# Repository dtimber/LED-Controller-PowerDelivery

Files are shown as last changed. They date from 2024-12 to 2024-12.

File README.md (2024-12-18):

# LED-Controller-PowerDelivery
ESP8266 LED Controller with USB PD input for WS2812B/SK6812 LEDs specially made for monitor backlighting with [WLED](https://kno.wled.ge/) and [Lightpack](https://github.com/psieg/Lightpack).

[Video example @ YouTube](https://youtu.be/EE_DajBsjAQ)

LED Controller can be attached to VESA 75 / 100 monitor mount using the case included in this repo:

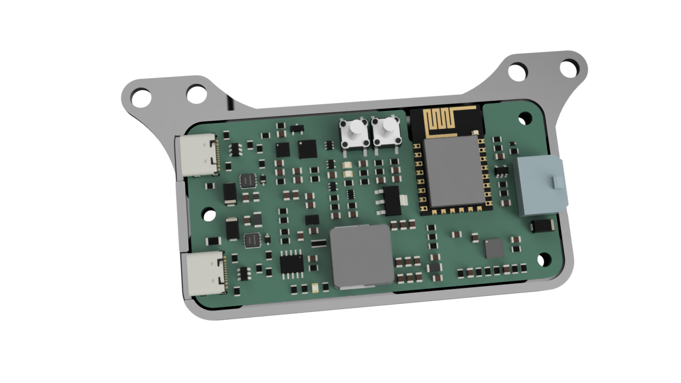
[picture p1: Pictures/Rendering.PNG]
Front


**Features:**
* Integrated 5 V buck converter for output currents up to 5 A (25 W). Minimizes risk of LED flickering / wrong colors caused by voltage drop by power supply cables, connectors, etc.
* Firmware can be flashed without additional USB PD supply connected to J1. Simply use J2 for programming.
* Single cable connection (power + data) possible via J1 (for PCs with USB PD compatible motherboards / extension cards [e.g. Inateck KU8212 / Delock 89001])
* LED power output protected by electronic fuse (output will be cut off if current is > 5 A / auto-retry after 400 ms)

**Required WLED GPIO Settings:**
* GPIO2 -> LED data output
* GPIO15 -> LED power output (WLED relay function)

**Additional Parts required:**
* 1x USB Power Delivery Supply with at least 30 W (15 V / 2 A)
* 1x USB Type C to C cable
* 3x M3 insert nuts (outer diameter: 4.6 mm / length: 6 mm) for the case
* 3x M3 screws (countersunk head e.g. ISO 10642 / length: 12 mm) for the case
* 1x connector 538-43645-0300 for the LED stripe cable
* 3x contacts 43030-0007 for the LED stripe cable

**Measured buck converter efficiency:**

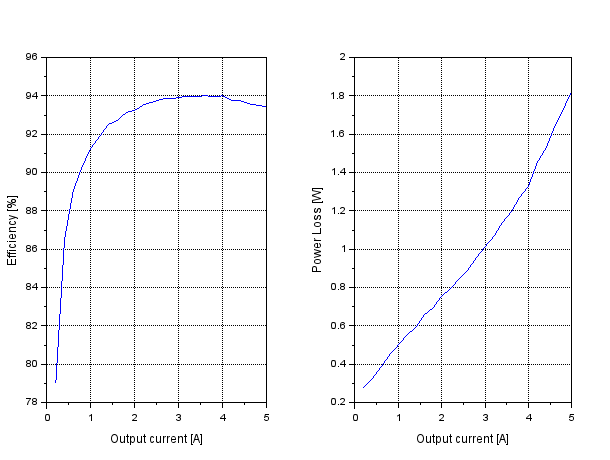
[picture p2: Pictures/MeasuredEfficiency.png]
Efficiency


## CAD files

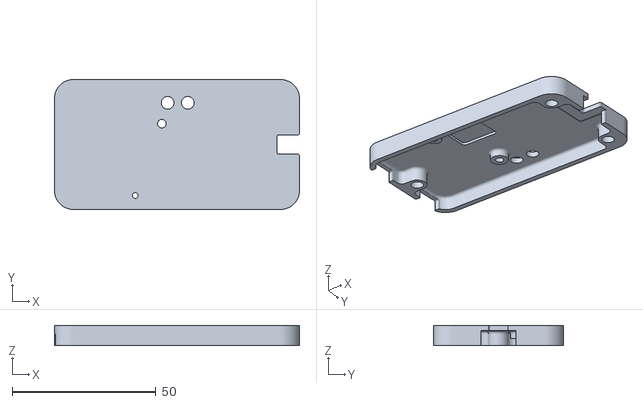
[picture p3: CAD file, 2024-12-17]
Case/LED-Controller-PD-UpperCase-Rev1.2.stl
85.2 x 45.2 x 7.00

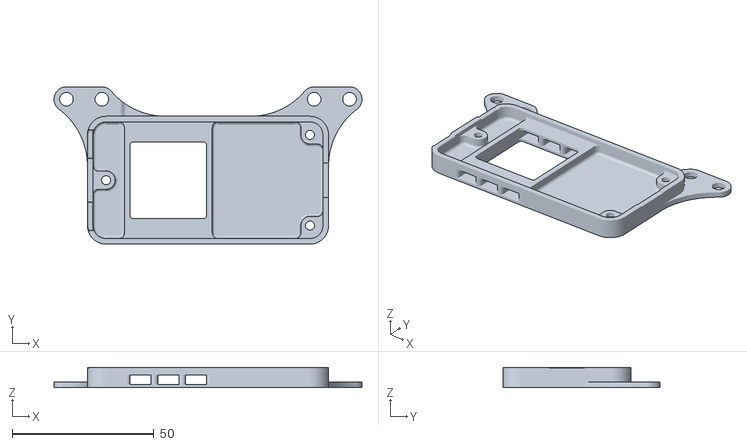
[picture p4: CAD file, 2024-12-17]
Case/LED-Controller-PD-LowerCase-Rev1.2.stl
108.8 x 55.6 x 7.10

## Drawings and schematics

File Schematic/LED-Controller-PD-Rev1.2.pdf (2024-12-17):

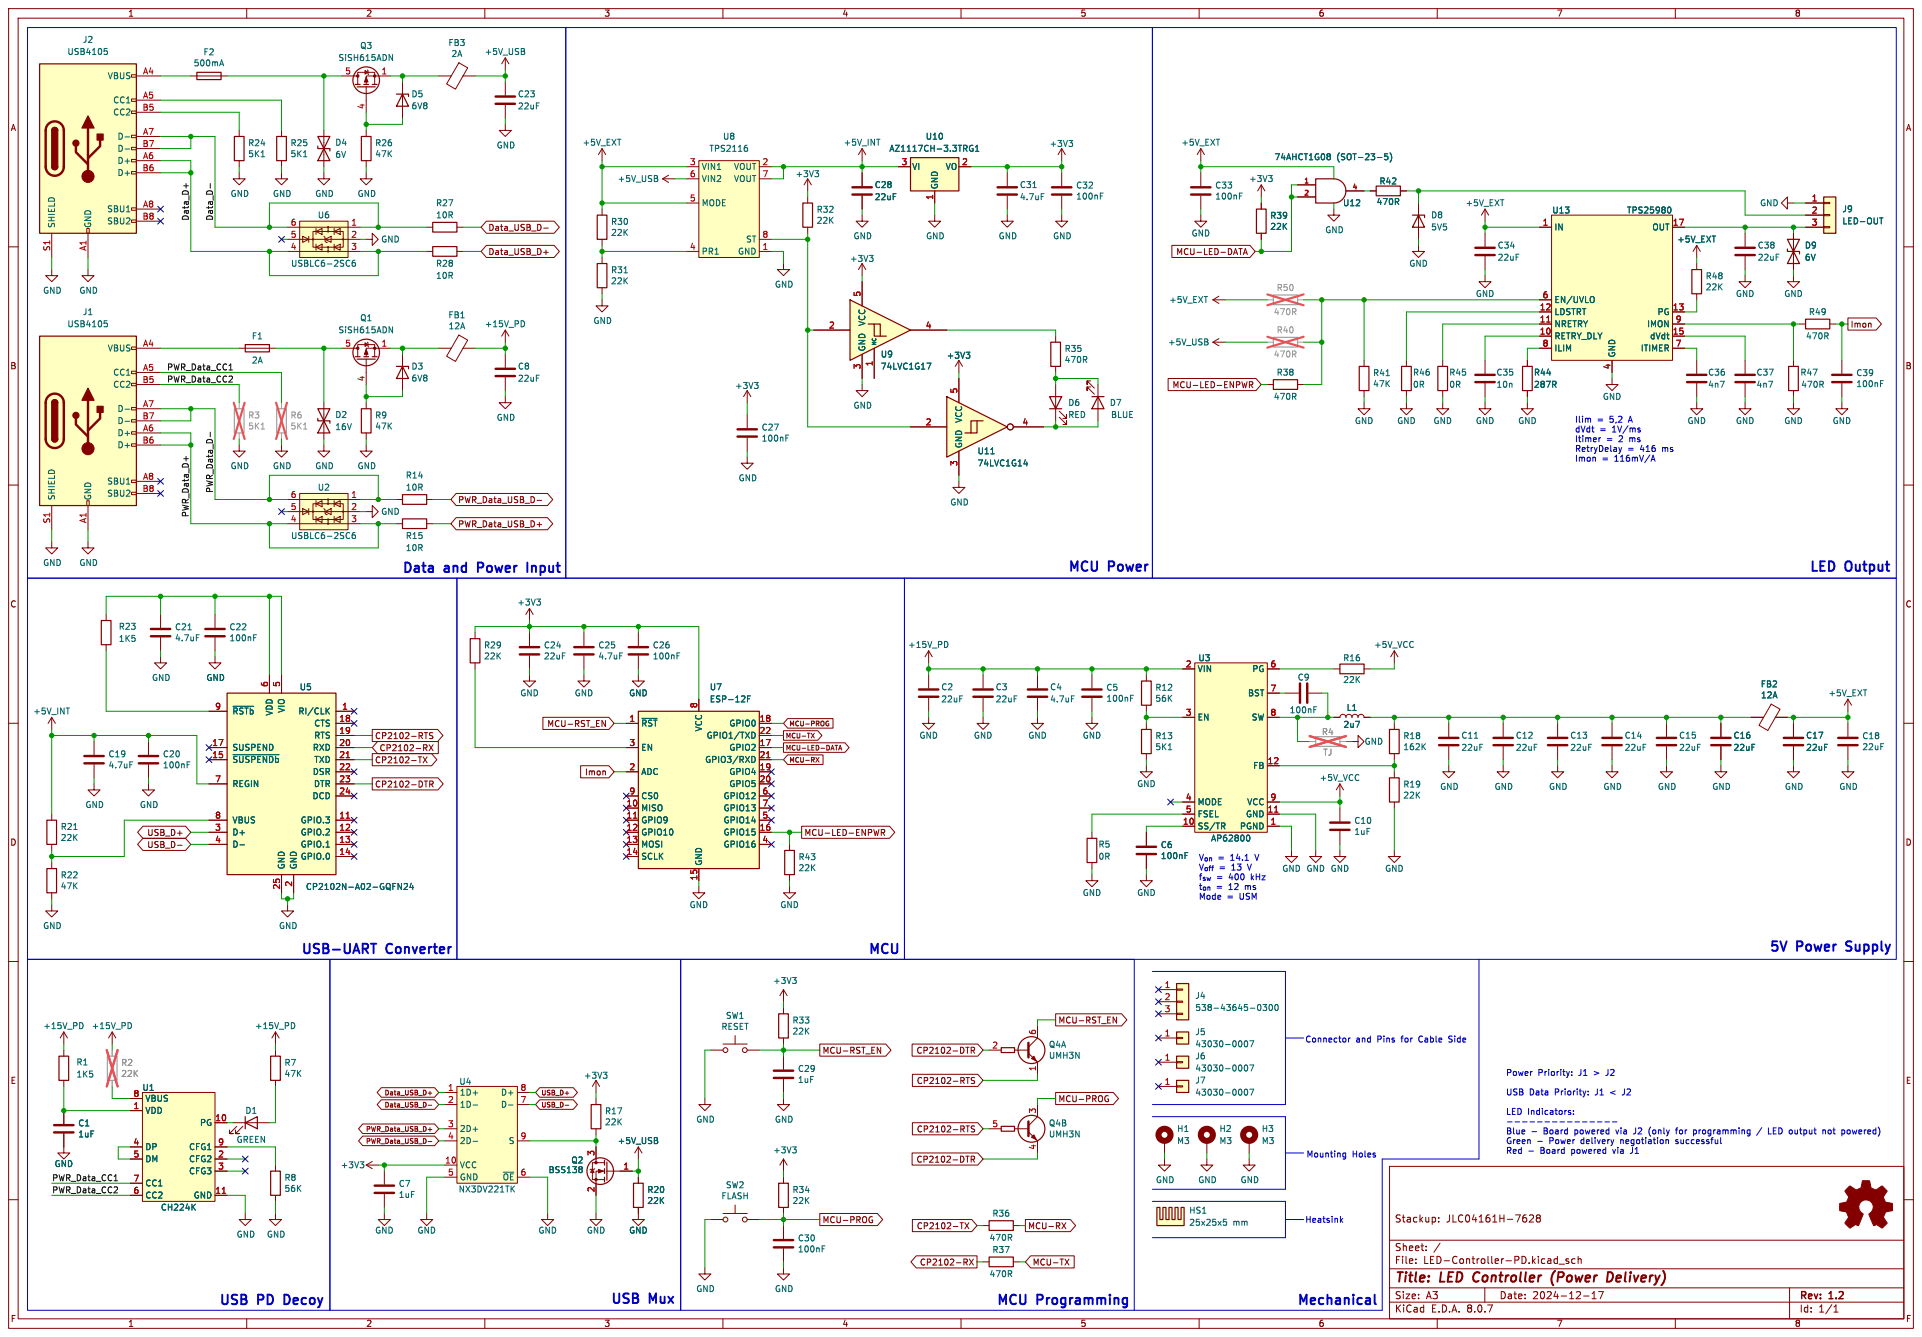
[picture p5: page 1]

Ilim = 5,2 A
dVdt = 1V/ms
Itimer = 2 ms RetryDelay = 416 ms

Data and Power Input

Mounting Holes MCU Power

6 REGIN 7 VBUS 8 ~{RSTb} 9 GND

6 REGIN 7 VBUS 8 ~{RSTb} 9 U5CP2102N-A02-GQFN24 GND

2 RXD 20 TXD 21 DSR 22 DTR 23 DCD 24 GND 25 D+ 3 D- 4 VIO

V_{off}= 13 V
f_{sw}= 400 kHz
t_{on}= 12 ms Mode = USM
